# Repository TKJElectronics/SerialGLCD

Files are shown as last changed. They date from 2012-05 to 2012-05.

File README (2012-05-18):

The code is released under the GNU General Public License.

This is the firmware and PCB for the SerialGLCD board by Kristian Lauszus, TKJ Electronics 2012.

For it to work move ks0108_Arduino.h into the glcd library folder like so: Arduino/libraries/glcd/config/ks0108_Arduino.h
Also remember to solder the solderjumper according to your Pinout (see http://www.arduino.cc/playground/Code/GLCDks0108).
The glcd library can be found at the following link: http://code.google.com/p/glcd-arduino/

For more information see my blog at http://blog.tkjelectronics.dk/ or send me an email at kristianl at tkjelectronics dot dk.

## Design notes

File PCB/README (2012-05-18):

The Gerber files are for ordering at http://www.dorkbotpdx.org/wiki/pcb_order

For more information see my blog at http://blog.tkjelectronics.dk/ or send me an email at kristianl at tkjelectronics dot dk.

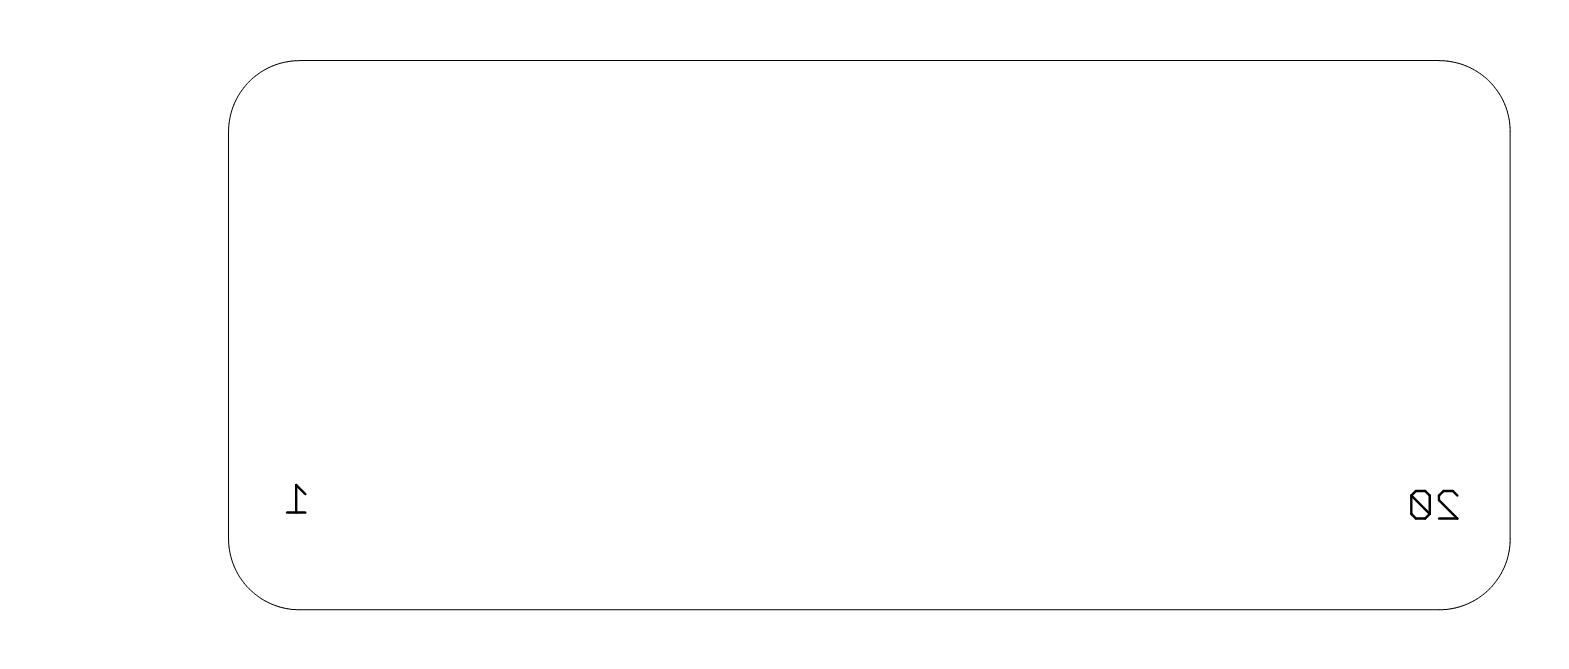
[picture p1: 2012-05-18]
PCB/Images for Gerber files/SerialGLCD.bottomsilkscreen.ger.png

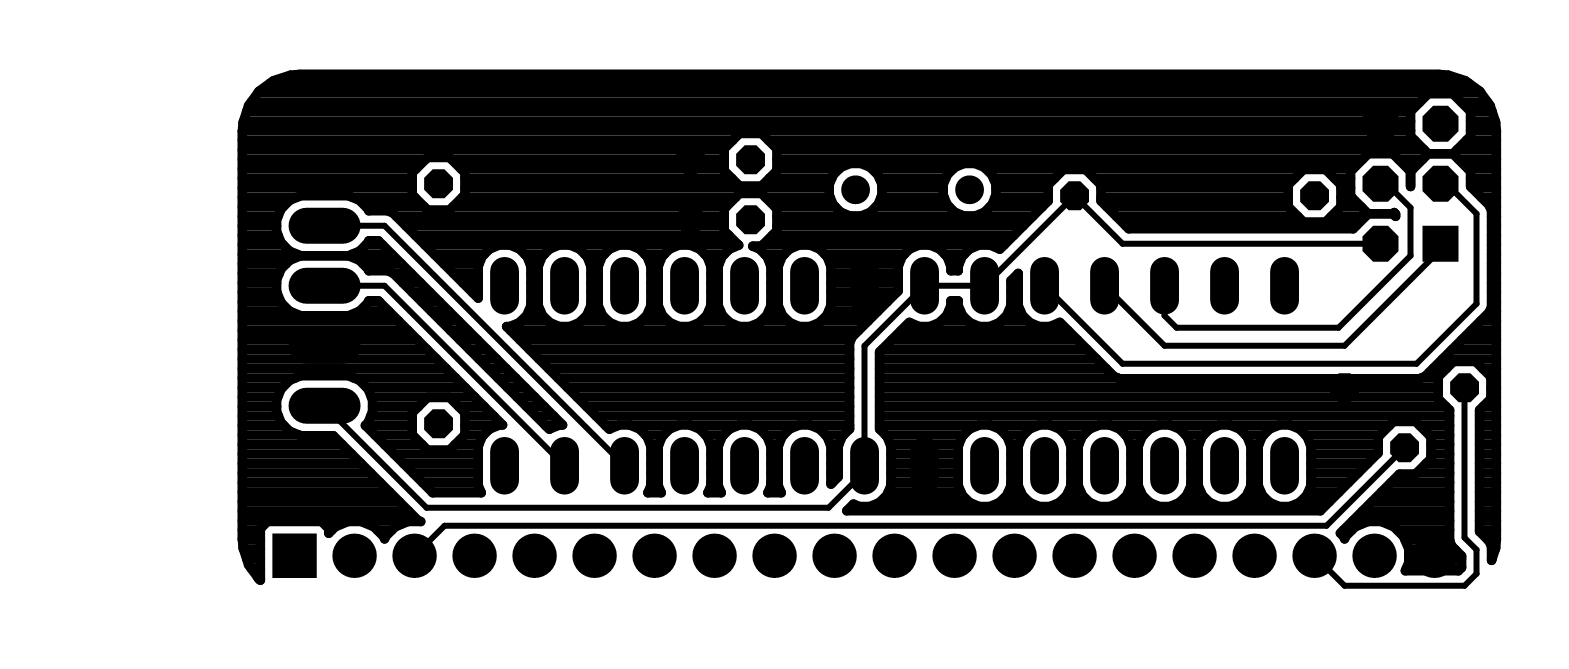
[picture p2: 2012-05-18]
PCB/Images for Gerber files/SerialGLCD.bottomlayer.ger.png

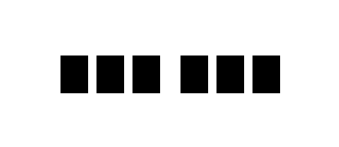
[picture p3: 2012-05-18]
PCB/Images for Gerber files/SerialGLCD.tcream.ger.png

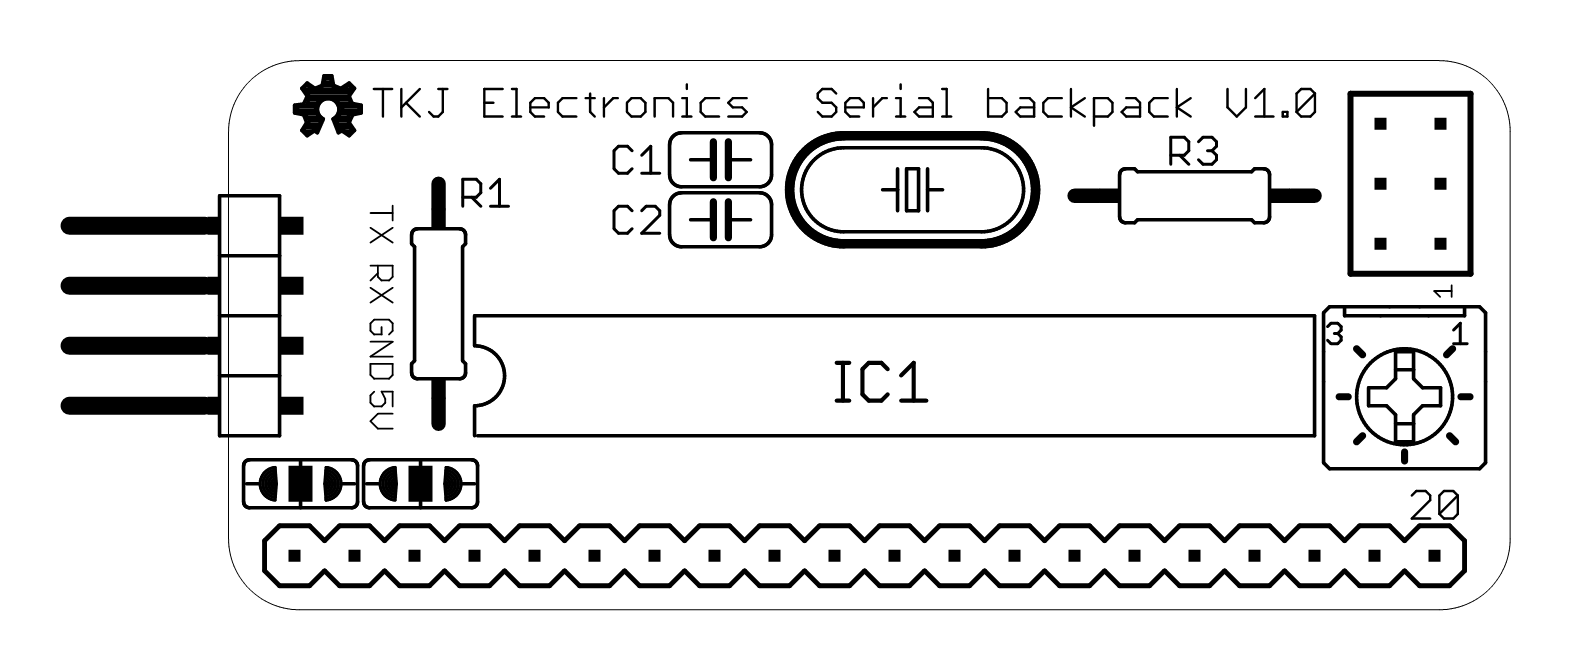
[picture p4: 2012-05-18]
PCB/Images for Gerber files/SerialGLCD.topsilkscreen.ger.png

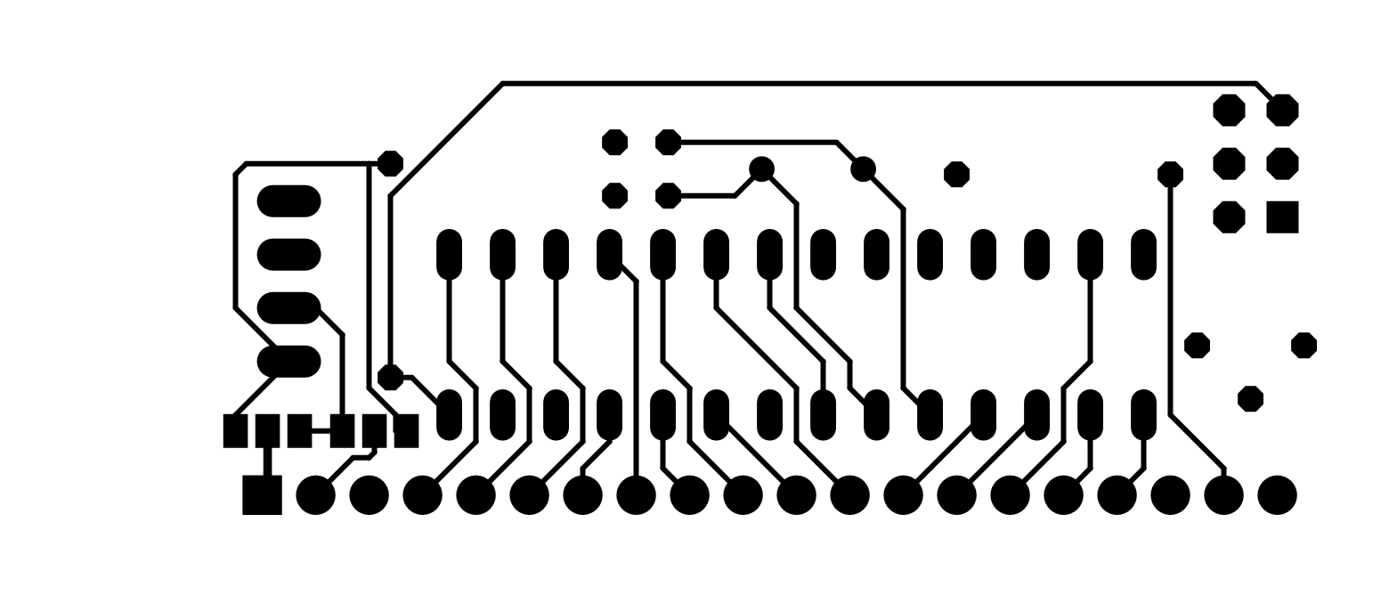
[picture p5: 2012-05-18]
PCB/Images for Gerber files/SerialGLCD.toplayer.ger.png

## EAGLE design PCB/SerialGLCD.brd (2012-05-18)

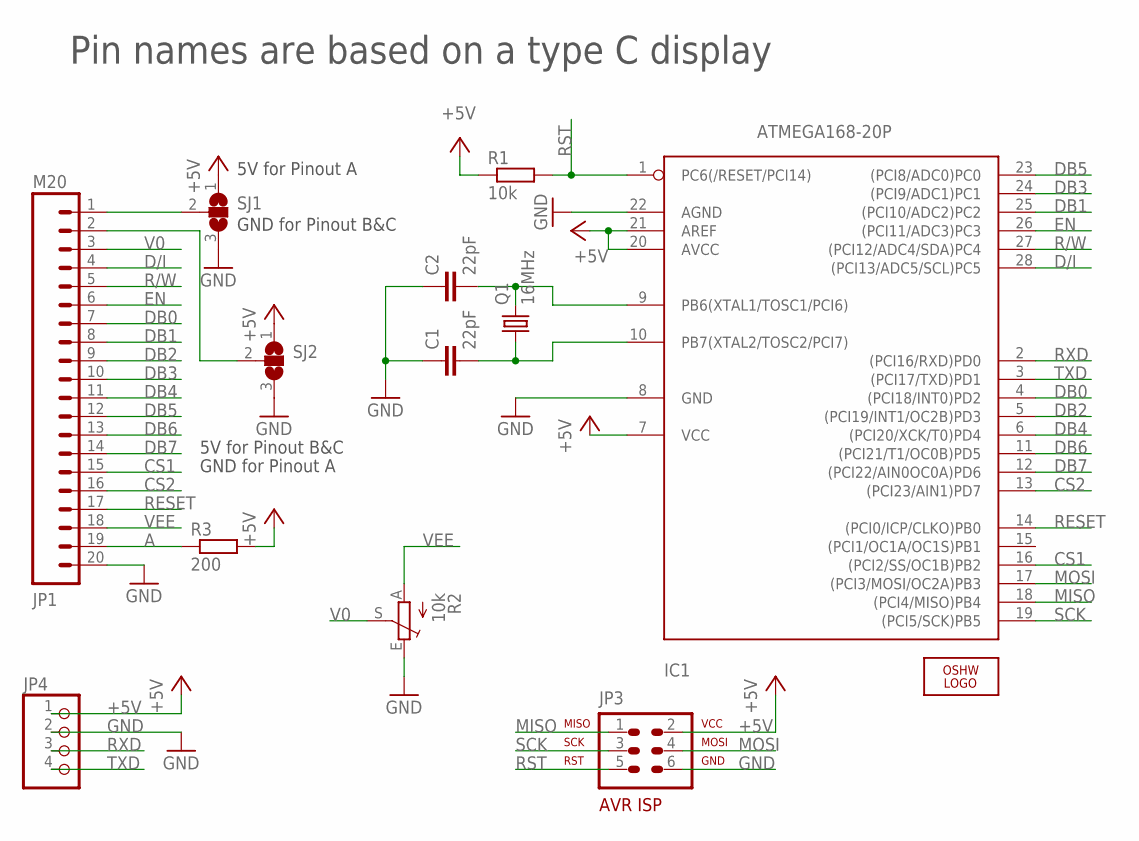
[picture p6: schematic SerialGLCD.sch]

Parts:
C1, C2: 22pF; C025-024X044
IC1: ATMEGA168-20P; DIL28-3
JP1: M20; 1X20
JP3: AVR-ISP-6VERT; AVR-ISP-6
JP4: PINHD-1X4/90; 1X04/90
LOGO1: OSHW_LOGO_FILLX0100-NT; OSHW_FILLX100_NOTEXT
Q1: 16MHz; HC49U-V
R1: 10k; 0207/10
R2: 10k; B25P
R3: 200; 0207/10
SJ1, SJ2: SJ2W; SJ_2

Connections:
+5V: IC1.7 (VCC), IC1.20 (AVCC), IC1.21 (AREF), JP3.2, JP4.1, R1.1, R3.2, SJ1.1, SJ2.1
A: JP1.19, R3.1
CS1: IC1.16 ((PCI2/SS/OC1B)PB2), JP1.15
CS2: IC1.13 ((PCI23/AIN1)PD7), JP1.16
D/I: IC1.28 ((PCI13/ADC5/SCL)PC5), JP1.4
DB0: IC1.4 ((PCI18/INT0)PD2), JP1.7
DB1: IC1.25 ((PCI10/ADC2)PC2), JP1.8
DB2: IC1.5 ((PCI19/INT1/OC2B)PD3), JP1.9
DB3: IC1.24 ((PCI9/ADC1)PC1), JP1.10
DB4: IC1.6 ((PCI20/XCK/T0)PD4), JP1.11
DB5: IC1.23 ((PCI8/ADC0)PC0), JP1.12
DB6: IC1.11 ((PCI21/T1/OC0B)PD5), JP1.13
DB7: IC1.12 ((PCI22/AIN0OC0A)PD6), JP1.14
EN: IC1.26 ((PCI11/ADC3)PC3), JP1.6
GND: C1.1, C2.1, IC1.8 (GND), IC1.22 (AGND), JP1.20, JP3.6, JP4.2, R2.E, SJ1.3, SJ2.3
MISO: IC1.18 ((PCI4/MISO)PB4), JP3.1
MOSI: IC1.17 ((PCI3/MOSI/OC2A)PB3), JP3.4
unnamed: JP1.1, SJ1.2
unnamed: JP1.2, SJ2.2
unnamed: C2.2, IC1.9 (PB6(XTAL1/TOSC1/PCI6)), Q1.2
unnamed: C1.2, IC1.10 (PB7(XTAL2/TOSC2/PCI7)), Q1.1
R/W: IC1.27 ((PCI12/ADC4/SDA)PC4), JP1.5
RESET: IC1.14 ((PCI0/ICP/CLKO)PB0), JP1.17
RST: IC1.1 (PC6(/RESET/PCI14)), JP3.5, R1.2
RXD: IC1.2 ((PCI16/RXD)PD0), JP4.3
SCK: IC1.19 ((PCI5/SCK)PB5), JP3.3
TXD: IC1.3 ((PCI17/TXD)PD1), JP4.4
V0: JP1.3, R2.S
VEE: JP1.18, R2.A

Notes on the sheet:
5V for Pinout A
GND for Pinout B&C
5V for Pinout B&C
GND for Pinout A
Pin names are based on a type C display

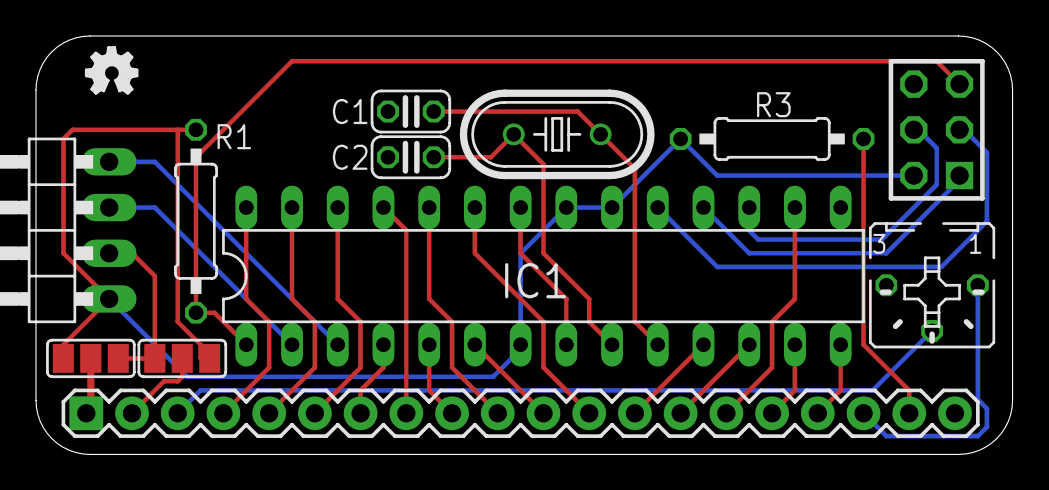
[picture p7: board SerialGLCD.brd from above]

Board: 2 copper layers, 54.3 x 23.2 mm, 13 parts (0 on the bottom side), 29 nets.

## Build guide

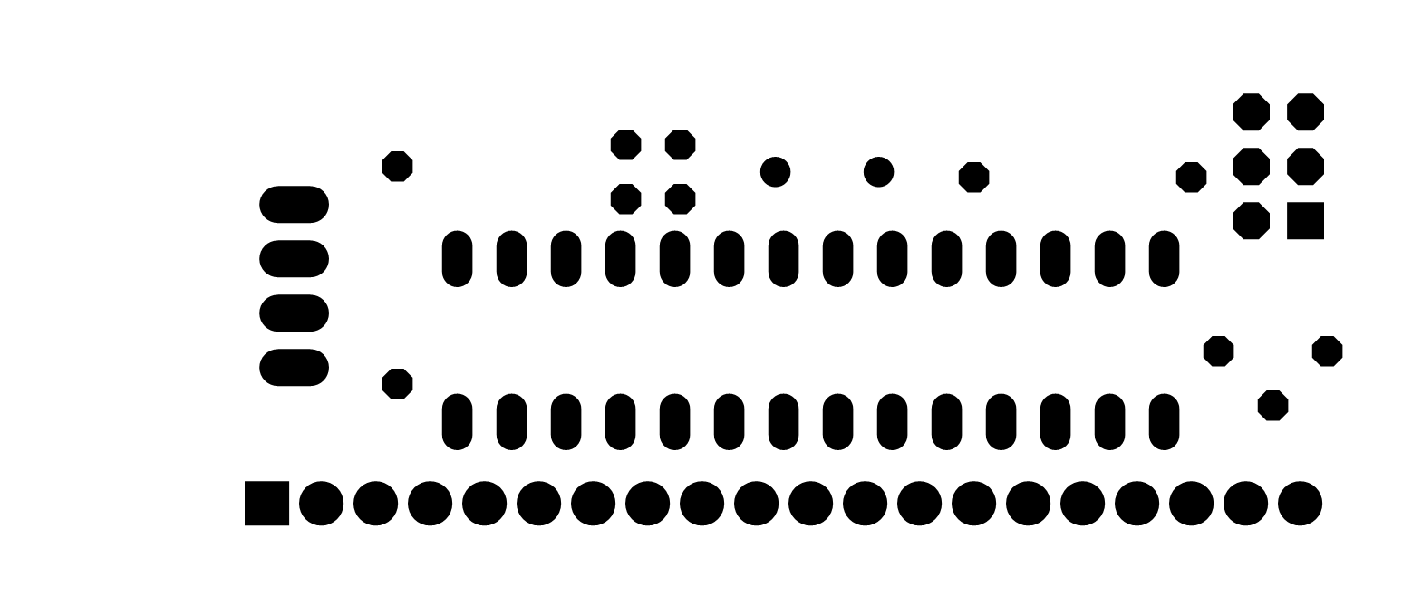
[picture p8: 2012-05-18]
PCB/Images for Gerber files/SerialGLCD.bottomsoldermask.ger.png

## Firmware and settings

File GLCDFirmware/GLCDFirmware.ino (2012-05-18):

#include <glcd.h>
#include <fonts/allFonts.h>

//#define DEBUG

byte c;
byte x1;
byte y1;
byte x2;
byte y2;
int color;
byte width;
byte height;
byte radius;

void setup() {
  GLCD.Init();   // initialise the library, non inverted writes pixels onto a clear screen
  GLCD.SelectFont(System5x7); // font for the default text area
  GLCD.ClearScreen(); 
  Serial.begin(115200); // Set baudrate  
}

void  loop() {
  if(Serial.available()) {
    c = Serial.read();
    if(c == 0x7C) { // Enter command mode
      delay(1);
      c = Serial.read();
      //Serial.println(c,HEX);
      switch(c) {
      case 0x00: // Clear screen
        GLCD.ClearScreen();
        break;
      case 0x01: // Set invert or noninverted
        color = Serial.read();
        if (color == -1) // Nothing is send
          color = 0;       
        GLCD.SetDisplayMode(color); // Send 0x00 for non-inverted mode and 0x01 for inverted
        break;

      case 0x02: // Set cursor to given x,y-coordinates
        x1 = Serial.read();
        y1 = Serial.read();
        GLCD.GotoXY(x1, y1);
        break;       
      case 0x03: // Set cursor based on current font 
        x1 = Serial.read();
        y1 = Serial.read();
        GLCD.CursorTo(x1, y1);
        break;

      case 0x04: // Set pixel
        x1 = Serial.read();
        y1 = Serial.read();
        color = Serial.read();
        GLCD.SetDot(x1, y1, color);
        break;       
      case 0x05: // Set pixels
        x1 = Serial.read();
        y1 = Serial.read();
        x2 = Serial.read();
        y2 = Serial.read();         
        color = Serial.read();
        GLCD.SetPixels(x1, y1, x2, y2, color);
        break;       

      case 0x06: // Draw line
        x1 = Serial.read();
        y1 = Serial.read();
        x2 = Serial.read();
        y2 = Serial.read();          
        color = Serial.read();
        GLCD.DrawLine(x1,y1,x2,y2,color);
        break;
      case 0x07: // Draw vertical line
        x1 = Serial.read();
        y1 = Serial.read();
        height = Serial.read();          
        color = Serial.read();
        GLCD.DrawVLine(x1,y1,height,color);
        break;     
      case 0x08: // Draw horizontal line
        x1 = Serial.read();
        y1 = Serial.read();
        width = Serial.read();          
        color = Serial.read();
        GLCD.DrawHLine(x1,y1,width,color);
        break;

      case 0x09: // Draw Circle
        x1 = Serial.read();
        y1 = Serial.read();
        radius = Serial.read();          
        color = Serial.read();
        GLCD.DrawCircle(x1, y1, radius, color);
        break;        
      case 0x0A: // Draw filled Circle
        x1 = Serial.read();
        y1 = Serial.read();
        radius = Serial.read();          
        color = Serial.read();
        GLCD.FillCircle(x1, y1, radius, color);
        break;        

      case 0x0B: // Draw Box
        x1 = Serial.read();
        y1 = Serial.read();
        width = Serial.read();
        height = Serial.read();                     
        color = Serial.read();
        GLCD.DrawRect(x1, y1, width, height, color);
        break;    
      case 0x0C: // Draw Filled Box
        x1 = Serial.read();
        y1 = Serial.read();
        width = Serial.read();
        height = Serial.read();              
        color = Serial.read();
        GLCD.FillRect(x1, y1, width, height, color);
        break;   
      case 0x0D: // Draw Inverted Box
        x1 = Serial.read();
        y1 = Serial.read();
        width = Serial.read();
        height = Serial.read();
        GLCD.InvertRect(x1, y1, width, height);
        break;        
      case 0x0E: // Draw Box with round edges
        x1 = Serial.read();
        y1 = Serial.read();
        width = Serial.read();
        height = Serial.read(); 
        radius = Serial.read();                  
        color = Serial.read();
        GLCD.DrawRoundRect(x1, y1, width, height, radius, color);
        break;

        //default:
        //Serial.println("Command not supported");
      }
    } 
    else {
      GLCD.write(c);   
      #ifdef DEBUG
      Serial.write(c);
      #endif
    }
  }
}

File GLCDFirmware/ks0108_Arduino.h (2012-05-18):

/*
 * ks0108_Arduino.h - User specific configuration for Arduino GLCD library 
 * This is a modified version for the SerialGLCD by Kristian Lauszus, TKJ Electronics 2012
 * Move into the glcd library folder like so: Arduino/libraries/glcd/config/ks0108_Arduino.h
 * Download the original library here: http://code.google.com/p/glcd-arduino/
 */

#ifndef GLCD_PIN_CONFIG_H
#define GLCD_PIN_CONFIG_H

/* Define name for pin configuration */
#define glcd_PinConfigName "ks0108-Arduino"

// Uncomment to set your pinout - remember to solder solderjumper too
//#define PinoutA
//#define PinoutB
#define PinoutC

#ifdef PinoutA
    /* Data pin definitions */
    #define glcdData0Pin        19
    #define glcdData1Pin        18
    #define glcdData2Pin        17
    #define glcdData3Pin        2
    #define glcdData4Pin        16
    #define glcdData5Pin        3
    #define glcdData6Pin        15
    #define glcdData7Pin        4

    /* Arduino pins used for Commands */
    #define glcdCSEL1        14
    #define glcdCSEL2        5

    #define glcdRW           10
    #define glcdDI           7
    #define glcdEN           8
    // Reset Bit
    #define glcdRES          6// Reset Bit
#else // PinoutB or PinoutC
    /* Data pin definitions */
    #define glcdData0Pin        2
    #define glcdData1Pin        16
    #define glcdData2Pin        3
    #define glcdData3Pin        15
    #define glcdData4Pin        4
    #define glcdData5Pin        14
    #define glcdData6Pin        5
    #define glcdData7Pin        6

    /* Arduino pins used for Commands */
    #ifdef PinoutB
        #define glcdCSEL1        7
        #define glcdCSEL2        10
    #else
        #define glcdCSEL1        10
        #define glcdCSEL2        7
    #endif

    #define glcdRW           18
    #define glcdDI           19
    #define glcdEN           17
    // Reset Bit
    #define glcdRES          8    // Reset Bit
#endif

#endif //GLCD_PIN_CONFIG_H

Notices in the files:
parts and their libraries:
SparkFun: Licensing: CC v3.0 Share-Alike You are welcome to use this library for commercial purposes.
